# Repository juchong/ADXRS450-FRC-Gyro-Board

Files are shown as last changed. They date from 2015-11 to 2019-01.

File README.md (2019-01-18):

## ***FRC TEAMS, BE AWARE THAT THE 2019 KICKOFF RELEASE IMAGE (v12) BREAKS COMPATIBILITY WITH ADI GYROS and IMUs! NI HAS RELEASED AN UPDATE SUITE (2019.1.0) ALONG WITH A NEW ROBORIO IMAGE (v13) THAT FIXES THE ISSUE. THE UPDATED INSTALLER CAN BE FOUND [HERE](http://www.ni.com/download/first-robotics-software-2017/7904/en/).***

# Analog Devices Gyro Board for FIRST Robotics
## A simple breakout board for interfacing the ADXRS450/ADXRS453 gyroscope with an FRC RoboRIO!

This repository is meant to document the development of the ADXRS450/453 donation board built by Analog Devices Inc. and donated to FIRST Robotics Competition teams. The gyro board incorporates a calibrated, single-axis yaw-rate sensor typically used in industrial and navigation applications. 

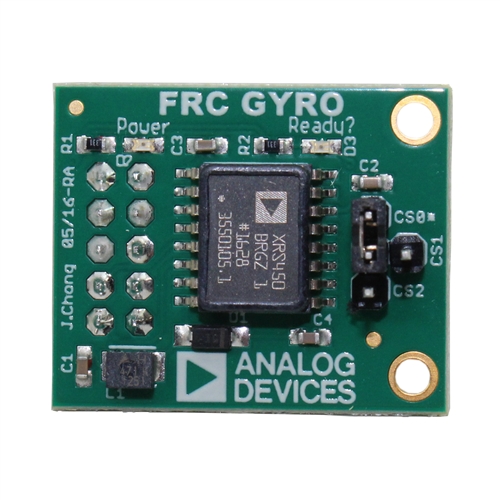
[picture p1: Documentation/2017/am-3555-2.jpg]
2017 Gyro Board - Image courtesy of AndyMark Inc.


## Why isn't your example code working?
A bug was introduced in the 2019 kickoff RoboRIO image which broke "Auto SPI." All ADI sensors currently offered to FRC teams rely on this feature to synchronously capture IMU data and feed it to the Zynq CPU for processing. The source of the bug was traced back to a RoboRIO image packaging issue and could be temporarily resolved on a v12 image by connecting to the serial/SSH terminal on the RoboRIO and executing the command "updateNIDrivers". This command forces the RoboRIO to re-compile the affected kernel module and fully resolves the issue. As of 01/17/2019, NI has released an updated [installer](http://www.ni.com/download/first-robotics-software-2017/7904/en/) (2019.1.0) that includes a pre-patched RoboRIO image (v13).

## ADXRS450 Features:

- Complete rate gyroscope on a single chip
- ±300°/sec angular rate sensing (single axis Z)
- High vibration rejection over a wide frequency range
- Excellent 25°/hour null offset stability
- Internally temperature compensated
- 2000 g powered shock survivability
- SPI digital output with 16-bit data-word
- Low noise and low power
- 3.3 V and 5 V operation
- -40°C to +105°C operation
- Ultra-small, light, and RoHS compliant

## Gyro Board Features:

- Designed to easily interface with the SPI port on the RoboRIO
- Software support is built into the official WPILib software distribution 
- Java, C++, and LabVIEW are fully supported
- *New in 2019* - SPI CS solder jumper for compatibility with other SPI devices on the same bus

## Getting Started:

Looking to get started with the sensor? Check out the FRC getting started guides available on the [Analog Devces Wiki](https://wiki.analog.com/first)!

## Build Your Own:

Circuit boards can be purchased from OshPark in quantities as few as 3. Links to the 2017 and 2019 PCB versions are provided below.

- [2019 Gyro Board](https://oshpark.com/shared_projects/y65Hwywf)
- [2017 Gyro Board](https://oshpark.com/shared_projects/hwu7OKyt)

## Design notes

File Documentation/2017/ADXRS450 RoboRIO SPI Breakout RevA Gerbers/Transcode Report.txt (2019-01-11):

   ---- Transcoding 'C:\Users\juanj\Dropbox\Eagle\Projects\FRC Projects\ADXRS450 RoboRIO SPI Breakout - 2017\Gerbers\ADXRS450 RoboRIO SPI Breakout RevA.gbo' ----   Mon Jun 27 11:01:12 2016

D10   --> D100
D11   --> D101
D12   --> D102
-----------------------------------------------------------------

   ---- Transcoding 'C:\Users\juanj\Dropbox\Eagle\Projects\FRC Projects\ADXRS450 RoboRIO SPI Breakout - 2017\Gerbers\ADXRS450 RoboRIO SPI Breakout RevA.gbs' ----   Mon Jun 27 11:01:12 2016

D10   --> D103
D11   --> D104
D12   --> D105
-----------------------------------------------------------------

   ---- Transcoding 'C:\Users\juanj\Dropbox\Eagle\Projects\FRC Projects\ADXRS450 RoboRIO SPI Breakout - 2017\Gerbers\ADXRS450 RoboRIO SPI Breakout RevA.gm1' ----   Mon Jun 27 11:01:12 2016

D10   --> D106
-----------------------------------------------------------------

   ---- Transcoding 'C:\Users\juanj\Dropbox\Eagle\Projects\FRC Projects\ADXRS450 RoboRIO SPI Breakout - 2017\Gerbers\ADXRS450 RoboRIO SPI Breakout RevA.gtl' ----   Mon Jun 27 11:01:12 2016

D11   --> D107
D12   --> D108
D13   --> D109
D14   --> D110
-----------------------------------------------------------------

   ---- Transcoding 'C:\Users\juanj\Dropbox\Eagle\Projects\FRC Projects\ADXRS450 RoboRIO SPI Breakout - 2017\Gerbers\ADXRS450 RoboRIO SPI Breakout RevA.gto' ----   Mon Jun 27 11:01:12 2016

D10   --> D443
D11   --> D444
D12   --> D445
D13   --> D446
D14   --> D447
D15   --> D448
D16   --> D449
D17   --> D450
D18   --> D451
D19   --> D452
D20   --> D453
D21   --> D454
D22   --> D455
D100  --> D456
D101  --> D457
D102  --> D458
D103  --> D459
D104  --> D460
D105  --> D461
D106  --> D462
D107  --> D463
D108  --> D464
D109  --> D465
D110  --> D466
-----------------------------------------------------------------

   ---- Transcoding 'C:\Users\juanj\Dropbox\Eagle\Projects\FRC Projects\ADXRS450 RoboRIO SPI Breakout - 2017\Gerbers\ADXRS450 RoboRIO SPI Breakout RevA.gtp' ----   Mon Jun 27 11:01:12 2016

D10   --> D467
D11   --> D468
D12   --> D469
D13   --> D470
D14   --> D471
D15   --> D472
-----------------------------------------------------------------

   ---- Transcoding 'C:\Users\juanj\Dropbox\Eagle\Projects\FRC Projects\ADXRS450 RoboRIO SPI Breakout - 2017\Gerbers\ADXRS450 RoboRIO SPI Breakout RevA.gts' ----   Mon Jun 27 11:01:12 2016

D10   --> D473
D11   --> D474
D12   --> D475
D13   --> D476
D14   --> D477
D15   --> D478
D16   --> D479
D17   --> D480
D18   --> D481
D19   --> D482
-----------------------------------------------------------------

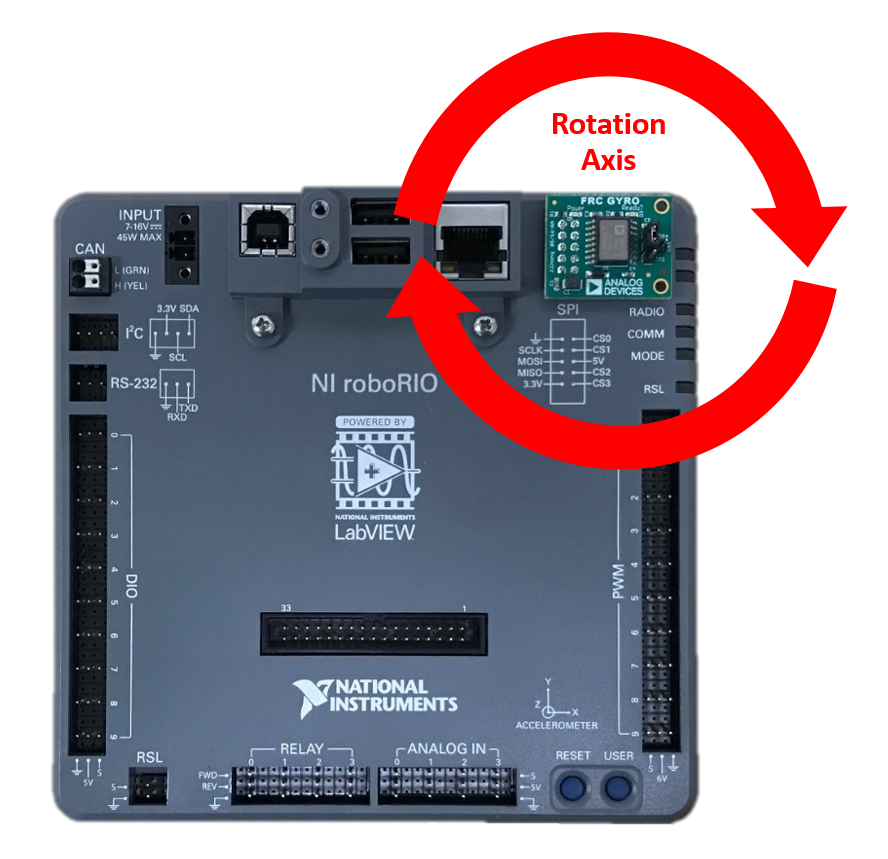
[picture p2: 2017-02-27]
Documentation/2017/rotation.png

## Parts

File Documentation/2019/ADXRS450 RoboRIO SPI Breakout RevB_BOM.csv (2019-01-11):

Qty-1 | Part References | Value | Mfg Part Num | Mfg Name | VID | Vendor Part Num | Description | Pkg Code
1 | C4 | 0.1uF | GRM188R71C104KA01D | Murata Electronics North America | DK | 490-1532-1-ND | CAP CER 0.1UF 16V 10% X7R 0603 | C0603
3 | C1, C2, C3 | 1uF | GRM188R61C105KA93D | Murata Electronics North America | DK | 490-1536-1-ND | CAP CER 1UF 16V 10% X5R 0603 | C0603
2 | R1, R2 | 330 | ERJ-3GEYJ331V | Panasonic Electronic Components | DK | P330GCT-ND | RES SMD 330 OHM 5% 1/10W 0603 | R0603
1 | L1 | 470uH | B82422H1474K | EPCOS Inc | DK | 495-2651-1-ND | FIXED IND 470UH 76MA 20 OHM SMD | L1210
1 | U1 | ADXRS45X-SOIC | ADXRS450BRGZ-RL | Analog Devices Inc | DK | ADXRS450BRGZ-RLCT-ND | SENS GYRO 300DEG/S DGTL 16SOIC | 16-SOIC
2 | D2, D3 | GREEN | LTST-C191KGKT | Lite-On Inc. | DK | 160-1446-1-ND | LED GREEN CLEAR THIN 0603 SMD | LED-0603
1 | D1 | MMSD4148T1 | MMSD4148T1G | ON Semiconductor | DK | MMSD4148T1GOSCT-ND | DIODE GEN PURP 100V 200MA SOD123 | SOD123
1 | J1 | OUTPUT | SSW-105-01-L-D-N | Samtec Inc | DK | SSW-105-01-L-D-N-ND | .025 SOCKET STRIPS | 2x05

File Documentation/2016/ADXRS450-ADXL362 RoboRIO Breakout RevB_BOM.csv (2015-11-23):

Qty-1 | Part References | Value | Package | Mfg Part Num | Mfg Name | VID | Vendor Part Num | Description | Pkg Code
1 | R2 | 0 | R0603 | RC0603JR-070RL | Yageo | DK | 311-0.0GRCT-ND | RES SMD 0.0 OHM JUMPER 1/10W | 0603-RES
3 | C4, C5, C7 | 0.1uF | 0603-CAP | GRM188R71C104KA01D | Murata Electronics North America | DK | 490-1532-1-ND | CAP CER 0.1UF 16V 10% X7R 0603 | C0603
4 | C1, C2, C3, C6 | 1uF | 0603-CAP | GRM188R61C105KA93D | Murata Electronics North America | DK | 490-1536-1-ND | CAP CER 1UF 16V 10% X5R 0603 | C0603
1 | R1 | 330 | R0603 | ERJ-3GEYJ331V | Panasonic Electronic Components | DK | P330GCT-ND | RES SMD 330 OHM 5% 1/10W 0603 | R0603
1 | L1 | 470uH | 1210 | B82422H1474K | EPCOS Inc | DK | 495-2651-1-ND | FIXED IND 470UH 76MA 20 OHM SMD | L1210
1 | U1 | ADXL362 | ADXL362 | ADXL362BCCZ-RL7 | Analog Devices Inc | DK | ADXL362BCCZ-RL7CT-ND | IC ACCEL DIG LO PWR 3AX 16LGA | 16-LGA
1 | U2 | ADXRS45X-SOIC | ADXRS45X | ADXRS450BRGZ-RL | Analog Devices Inc | DK | ADXRS450BRGZ-RLCT-ND | SENS GYRO 300DEG/S DGTL 16SOIC | 16-SOIC
1 | D2 | GREEN | LED-0603 | LTST-C191KGKT | Lite-On Inc. | DK | 160-1446-1-ND | LED GREEN CLEAR THIN 0603 SMD | LED-0603
1 | D1 | MMSD4148T1 | SOD123 | MMSD4148T1G | ON Semiconductor | DK | MMSD4148T1GOSCT-ND | DIODE GEN PURP 100V 200MA SOD123 | SOD123
1 | JP2 | OUTPUT | 2X5-SHROUDED_LOCK | SSW-105-01-L-D-N | Samtec Inc | Samtec | SSW-105-01-L-D-N | 2x5 Through Hole 0.1? Header Keyed | 2x05

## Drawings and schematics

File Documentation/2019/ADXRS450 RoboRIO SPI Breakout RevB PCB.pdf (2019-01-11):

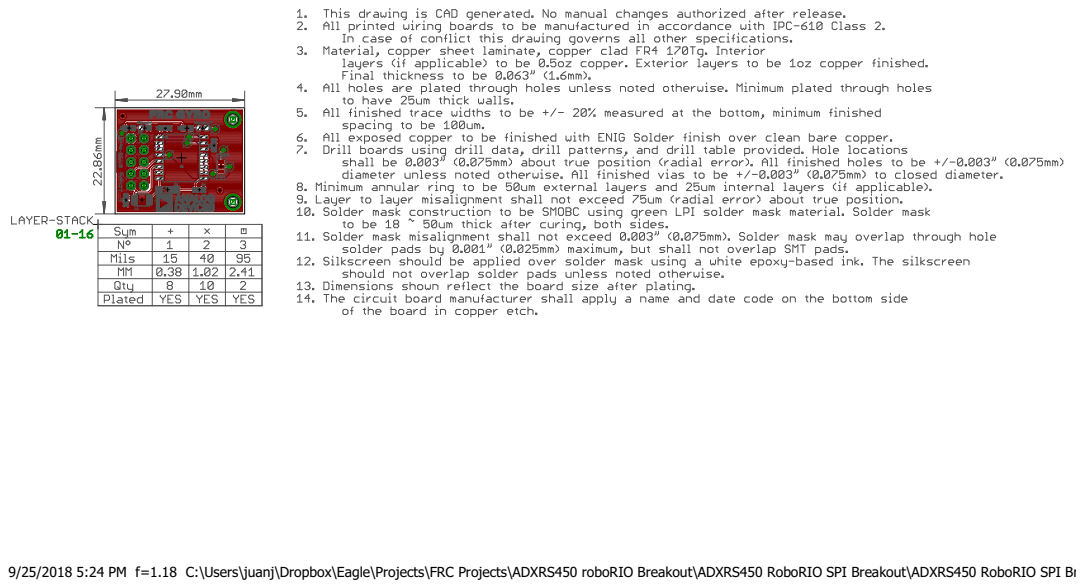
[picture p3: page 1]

9/25/2018 5:24 PM f=1.18 C:\Users\juanj\Dropbox\Eagle\Projects\FRC Projects\ADXRS450 roboRIO Breakout\ADXRS450 RoboRIO SPI Breakout\ADXRS450 RoboRIO SPI Breakout RevB.brd

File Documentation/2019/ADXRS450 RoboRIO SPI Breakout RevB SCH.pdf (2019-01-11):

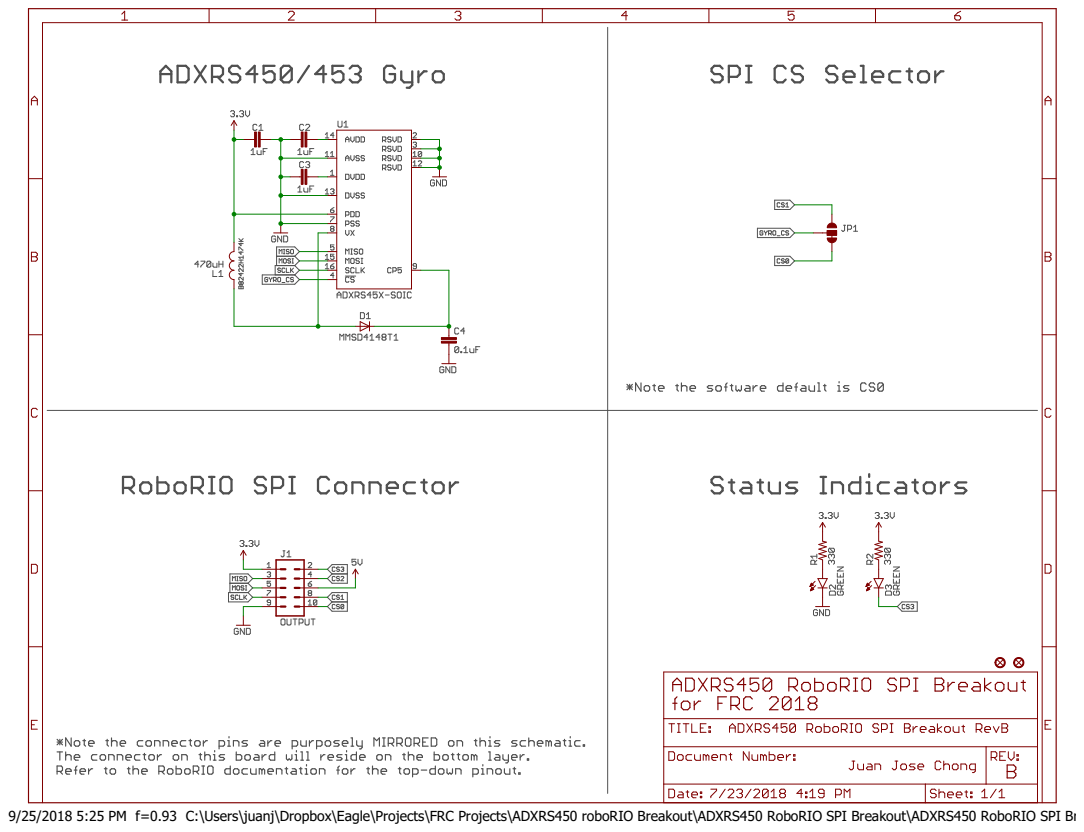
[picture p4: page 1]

9/25/2018 5:25 PM f=0.93 C:\Users\juanj\Dropbox\Eagle\Projects\FRC Projects\ADXRS450 roboRIO Breakout\ADXRS450 RoboRIO SPI Breakout\ADXRS450 RoboRIO SPI Breakout RevB.sch (Sheet: 1/1)

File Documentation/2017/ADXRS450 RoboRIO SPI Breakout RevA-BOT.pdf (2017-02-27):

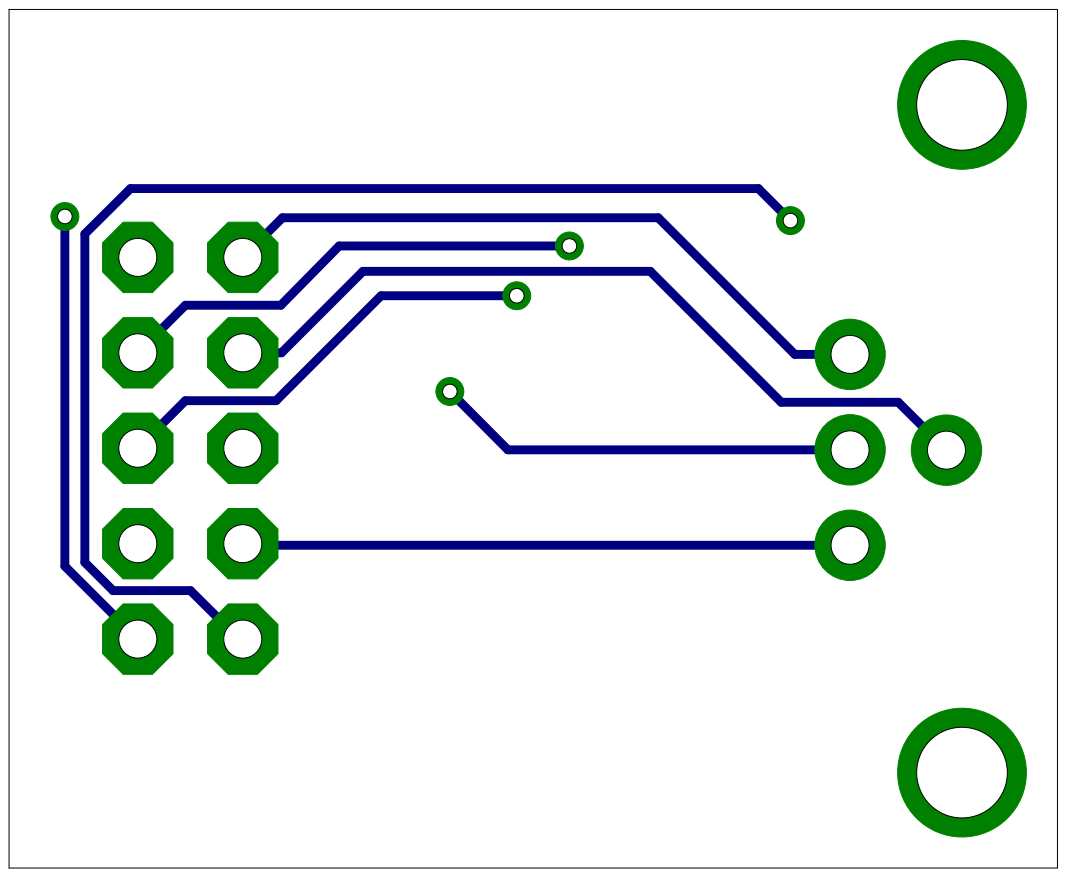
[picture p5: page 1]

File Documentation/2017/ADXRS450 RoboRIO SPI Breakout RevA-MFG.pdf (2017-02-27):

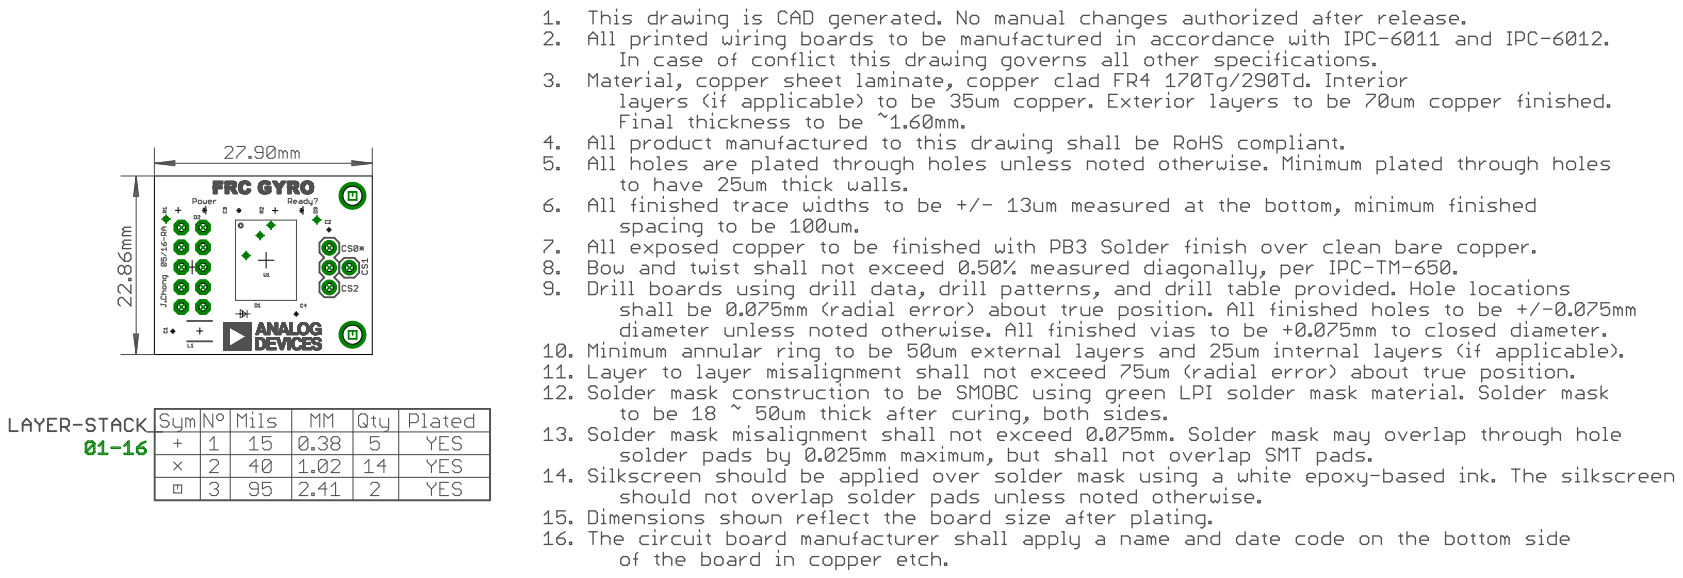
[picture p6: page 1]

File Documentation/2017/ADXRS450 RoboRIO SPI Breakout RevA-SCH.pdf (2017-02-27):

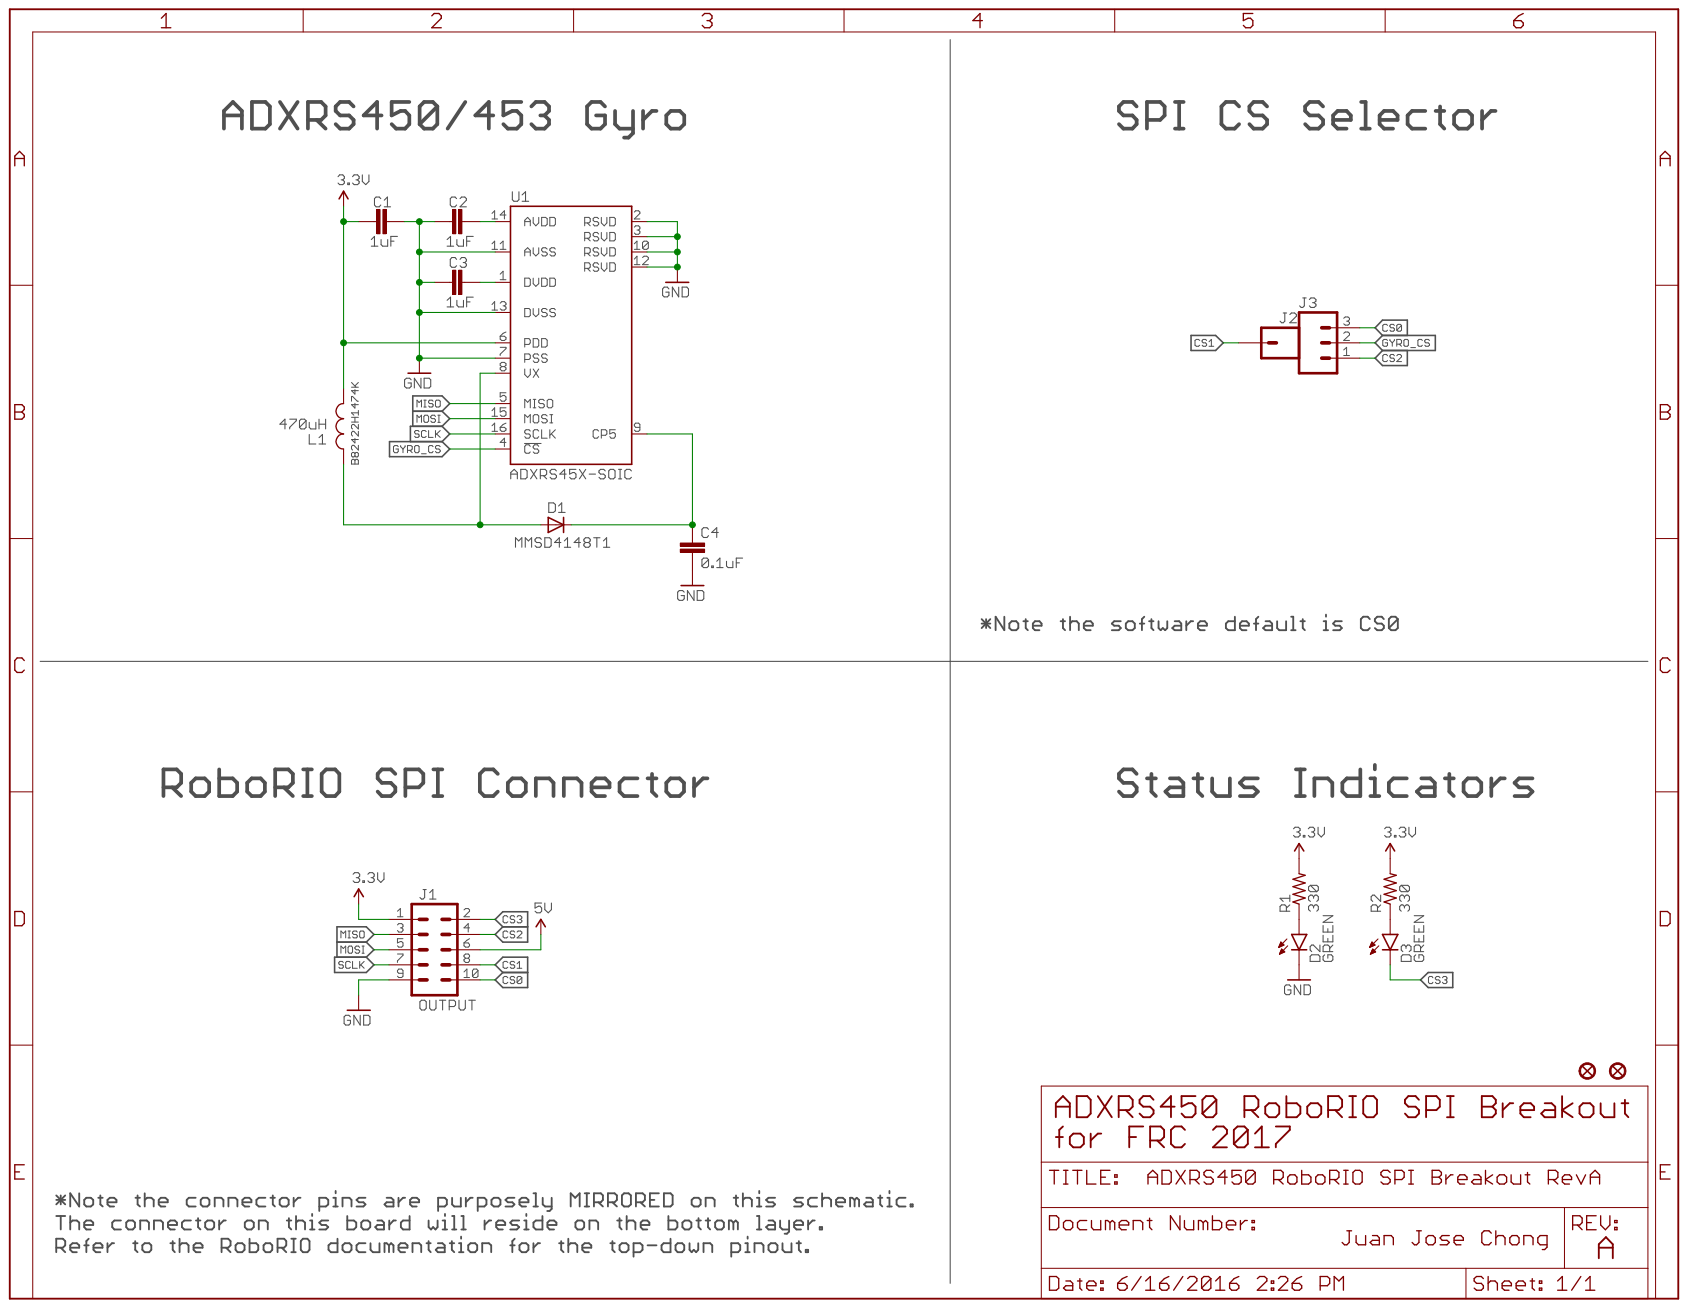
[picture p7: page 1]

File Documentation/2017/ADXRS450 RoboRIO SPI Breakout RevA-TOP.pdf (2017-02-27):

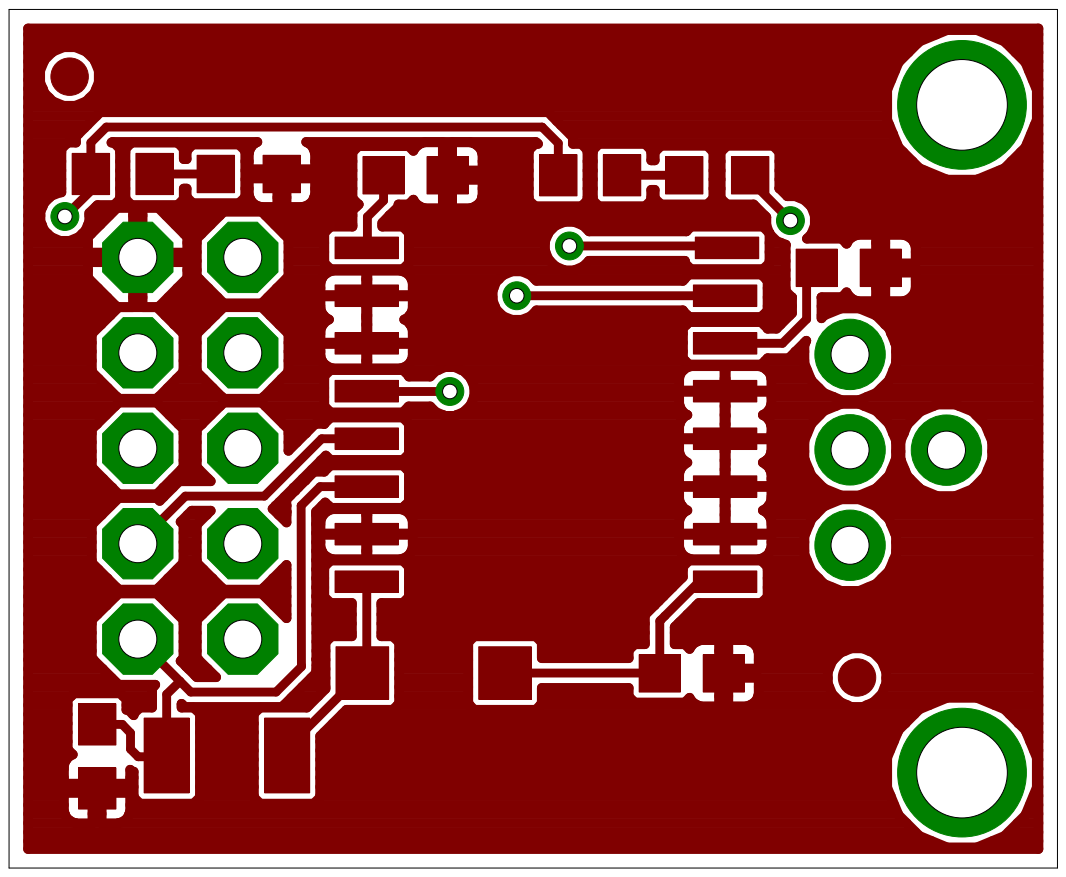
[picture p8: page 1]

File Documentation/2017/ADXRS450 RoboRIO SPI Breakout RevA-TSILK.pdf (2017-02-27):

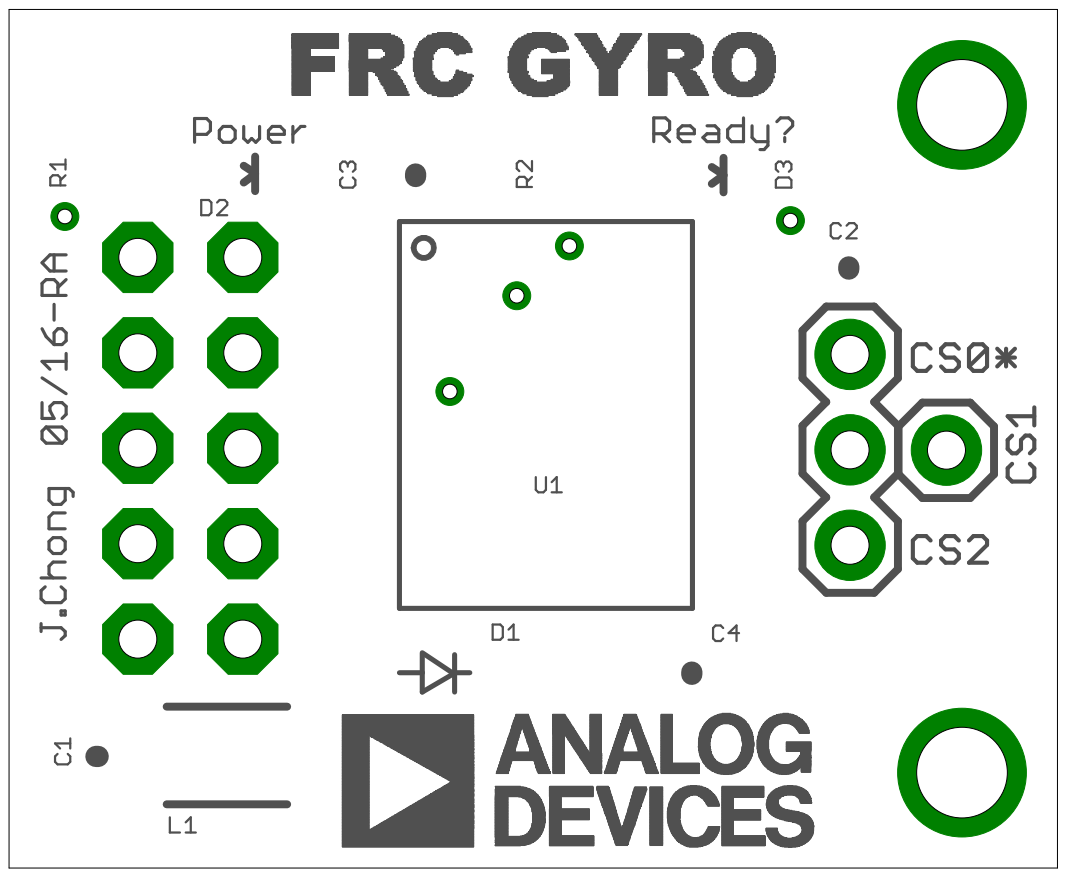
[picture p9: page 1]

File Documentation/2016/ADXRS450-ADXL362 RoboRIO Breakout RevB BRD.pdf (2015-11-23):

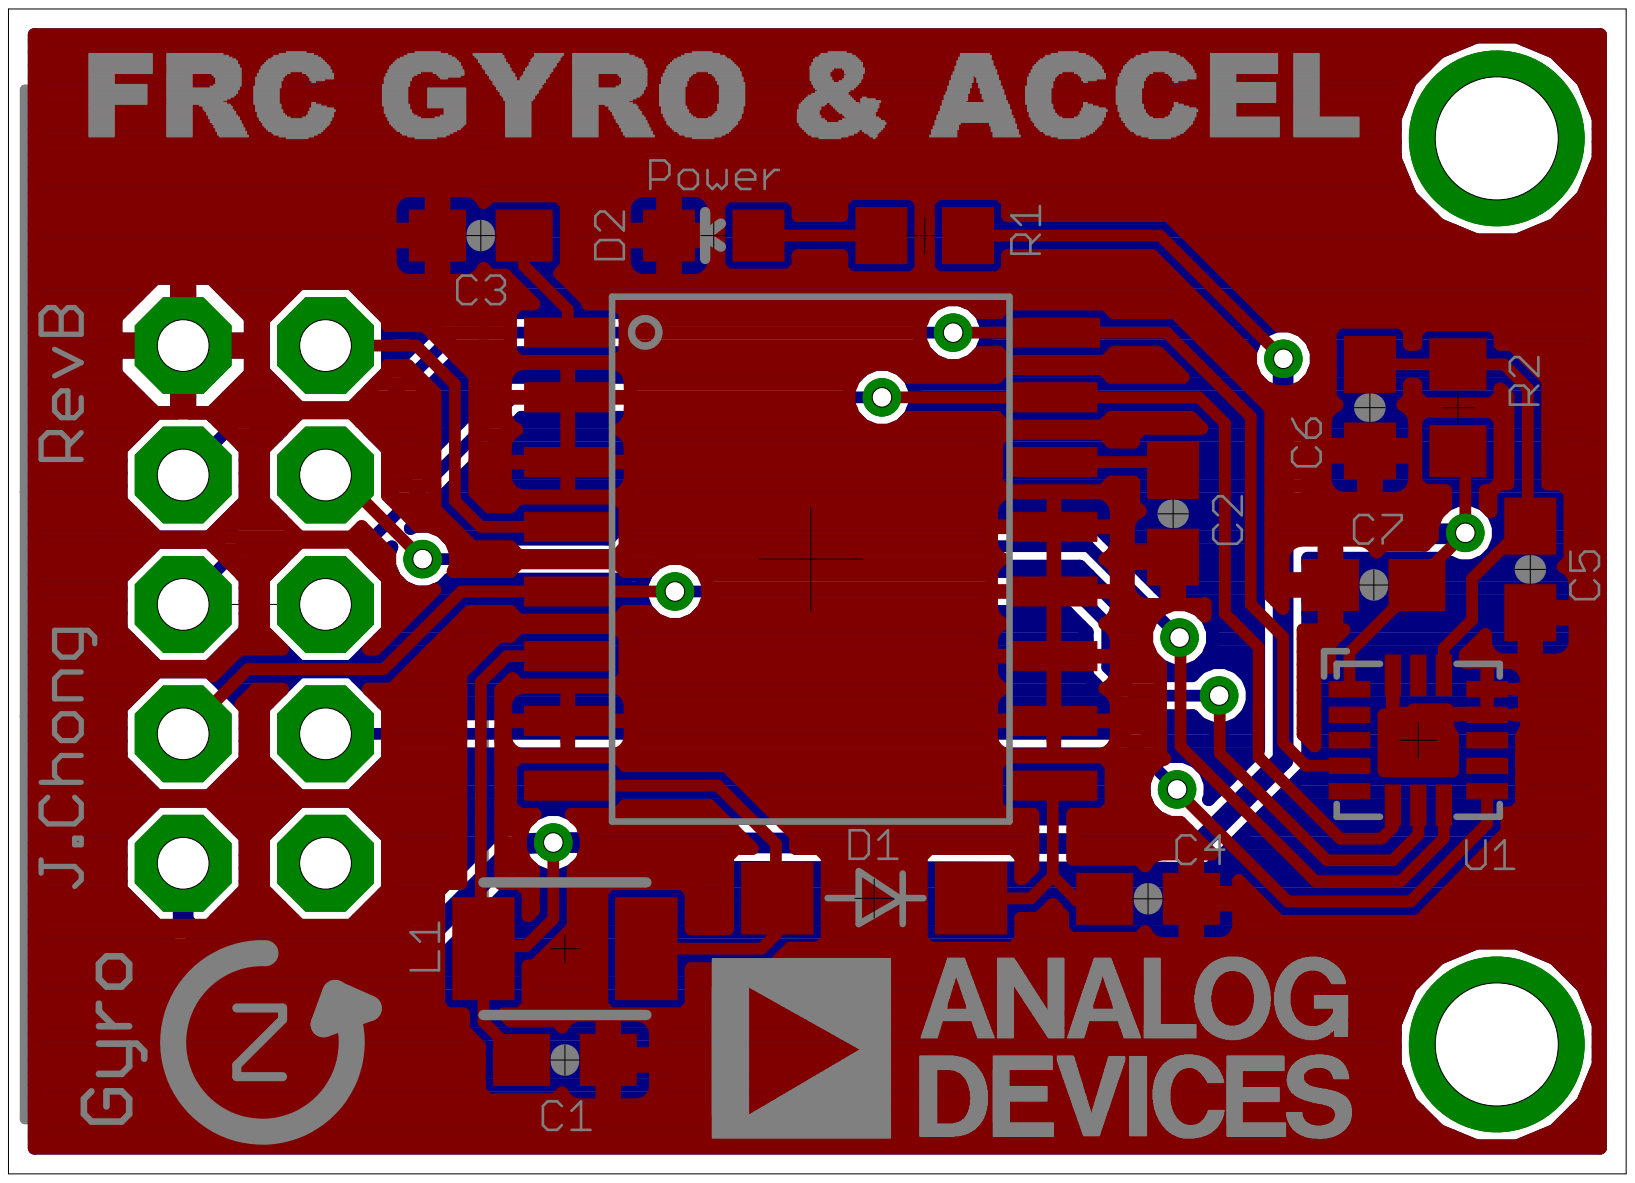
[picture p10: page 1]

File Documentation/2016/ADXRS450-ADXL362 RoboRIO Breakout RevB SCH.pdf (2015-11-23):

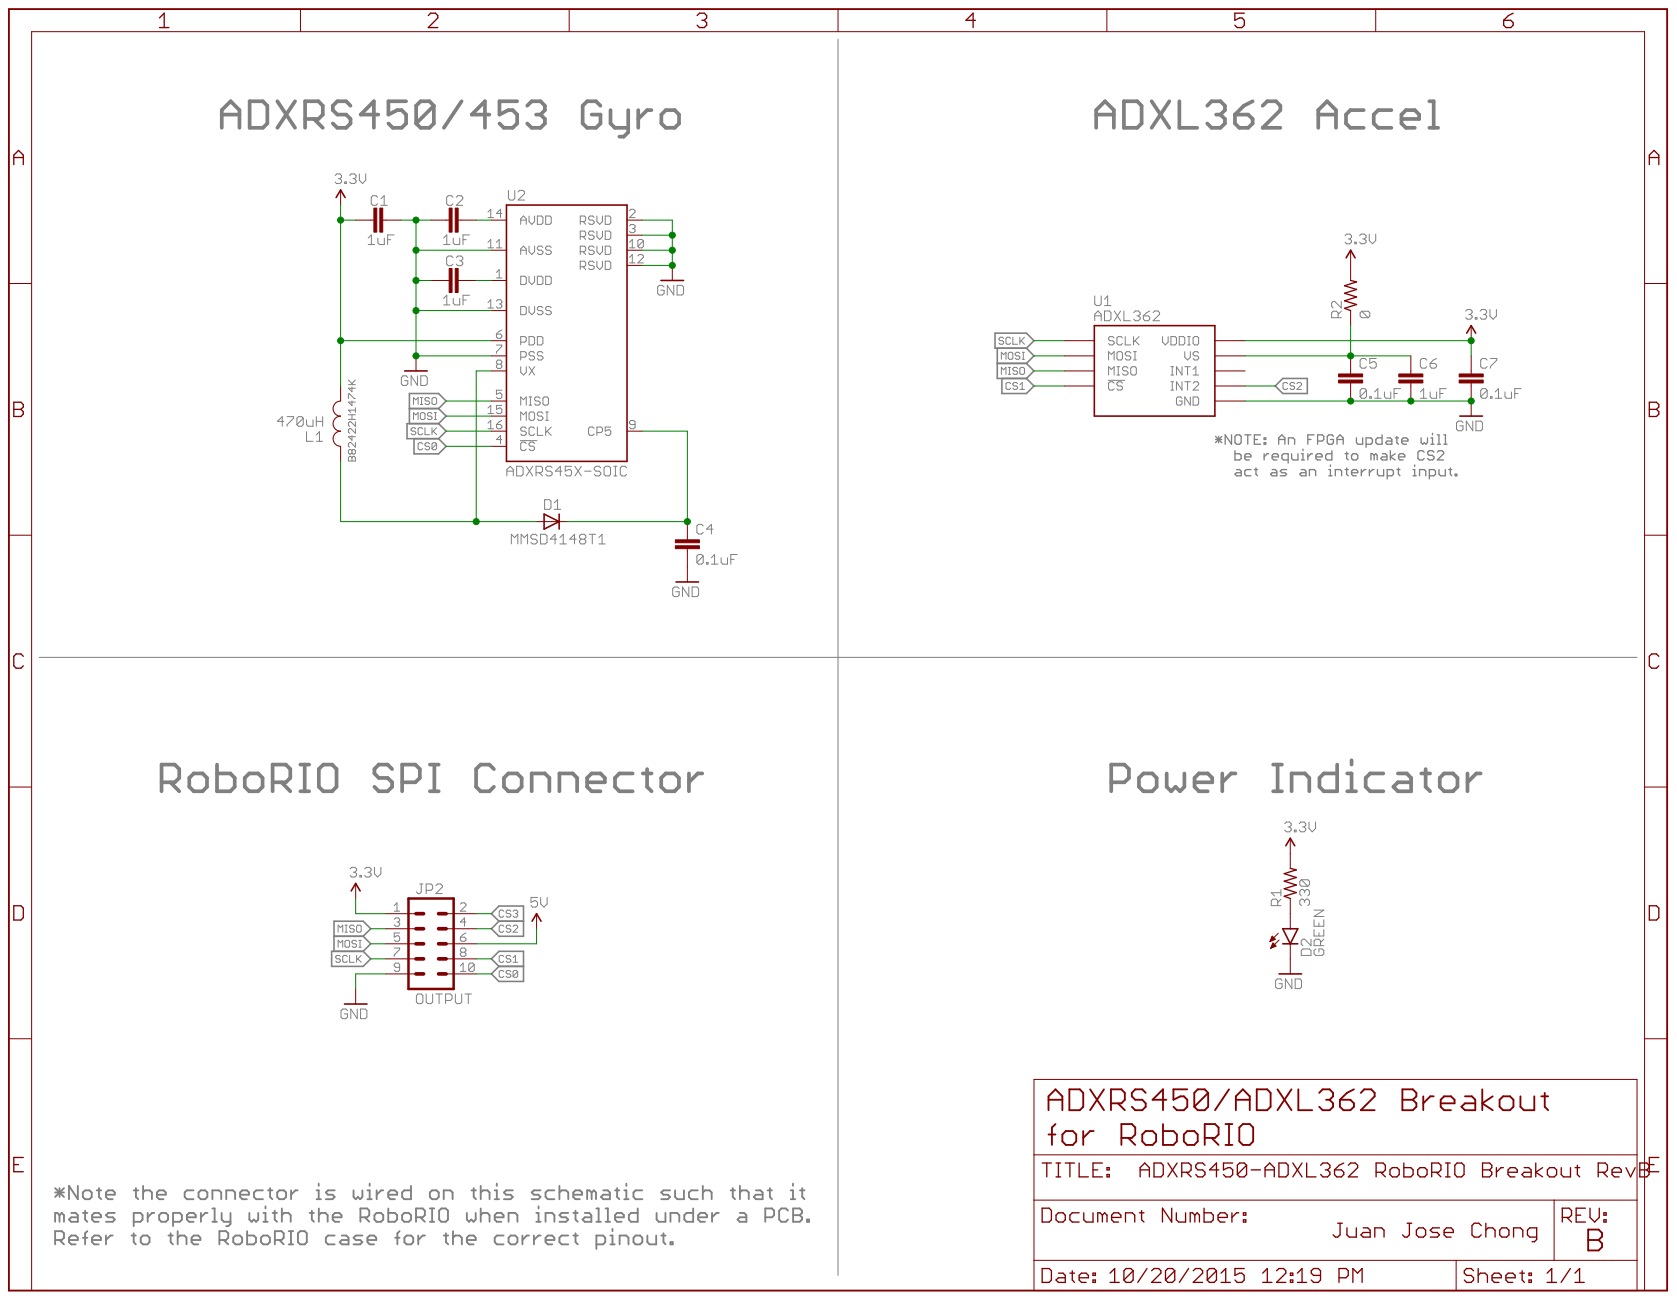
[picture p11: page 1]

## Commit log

2015-03-17 Changed calibration # of samples to 1 second
2015-03-18 Change Calibration Routine
    Change Calibration Routine to be in a separate loop with specific and
    faster timing (2k samples in 1 second)
    Added all of the ADXRS453 example files from WPIlib to this project to
    avoid any dependency issues
2015-04-14 Fixed scaling issue during calibration
    The offset calibration averages the sensor output * the scaling factor.
    It was subtracting this offset AFTER the summing portion accounting for
    the time.
    Cleaned up the example a little bit
2015-10-03 Updated the RoboRIO Example with the final, prototype, circuit board and added a control for the "Reset" function.
2015-10-03 Added a "Calibrating Finished?" boolean to the FGV which is updated once the gyro is calibrated. It may be read from the "Get Angle" function. Added some documentation to the gyro loop and included t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
2015-10-03 Updated icons, fixed RefNum Registry Get/Set not being updated, added the calibrating finished output to the GetRate VI, and replaced the image in the gyro example VI.
2015-11-23 Removed a missing reference in the Gyro typedef and updated all dependent VIs. Renamed the project to "FRC Gyro and Accel"
2015-11-23 Updated documentation.
    [ADXRS450-ADXL362 RoboRIO Breakout RevB_BOM.csv]
2017-02-27 Moved files around in project. Modified project name, etc.
    [ADXRS450-ADXL362 RoboRIO Breakout RevB_BOM.csv]
2017-02-27 Added pictures of the gyro board.
2019-01-11 Added 2019 PCB documentation and updated README.md
    [ADXRS450 RoboRIO SPI Breakout RevA.gbl, ADXRS450 RoboRIO SPI Breakout RevA.gbo, ADXRS450 RoboRIO SPI Breakout RevA.gbp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]
